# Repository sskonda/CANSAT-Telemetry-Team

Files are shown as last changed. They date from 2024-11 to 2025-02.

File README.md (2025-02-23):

# Telemetry Subsystem for SSDC CANSAT Competition  

## Overview  
This repository contains the telemetry subsystem code and resources for the SSDC CANSAT competition. It focuses on the integration and operation of sensors, motors, and the power subsystem, which are essential components for gathering, processing, and transmitting flight data. The repository does **not** include the flight software but provides all necessary libraries, configuration files, and guidelines for testing and deploying individual components.

## Project Background  
The CANSAT competition involves designing a small satellite (payload) and container that are deployed from a rocket. Upon reaching peak altitude, the container descends using a parachute, while the payload separates mid-flight and uses an auto-gyro system for controlled descent. During the mission, the payload must transmit telemetry data to the ground station at 1 Hz. 

The telemetry subsystem covered in this repository includes the following key responsibilities:
- **Collecting sensor data**: temperature, battery voltage, altitude, gyro rotation rate, acceleration, magnetic field, and GPS coordinates.
- **Managing power subsystems** to ensure consistent operation throughout the flight.
- **Handling data transmission** to the ground station.

## Repository Structure  
- **Individual Sensors Names**: Contains the necessary sensor and motor libraries, which must be uploaded to the microcontroller (e.g., Raspberry Pi Pico) for compatibility with the Thonny IDE.
- **CANSAT_PCB_Files**: Configuration files and scripts to manage power distribution and battery status monitoring.
- **`Sensor Integration/`**: Example code and test files for sensors such as temperature, GPS, gyroscopes, and magnetometers, ensuring accurate data collection.
- **`Motor Control/`**: Scripts to manage motors or actuators involved in the payload’s auto-gyro descent mechanism.

## Setup Instructions  
1. **Installing Libraries**:  
   - Place the include files (libraries) directly into the storage of the microcontroller (such as the Raspberry Pi Pico) to use them in Thonny.  
   - Main scripts for testing can remain in the development environment on your computer.

2. **Testing the Subsystem**:  
   Use individual test scripts provided in the repository to validate each sensor and motor module. Ensure that the telemetry data is transmitted to the ground station at the required **1 Hz interval** during testing.

## Software Raspberry Pi PIco connections for CANSAT (i.e. whcih GPIO Pins are connected to What)

 - **GP 6** PWM for LED to point Bottom Camera North
 - **GP 7 PWM** for Servo to point Bottom Camera North

 - **GP 8** BMP280 SDA
 - **GP 9** BMP280 SCL

 - **GP 12** Adafruit Ultimate GPS TX (UART Transmit)
 - **GP 13** Adafruit Ultimate GPS RX (UART Receive)

 - **GP 16** BNO055 SDA
 - **GP 17** BNO055 SCL

## Contribution Guidelines  
1. **Branching**: Use feature-specific branches to add or modify subsystem components.  
2. **Documentation**: Update the README or relevant code comments with clear descriptions of any changes.  
3. **Testing**: All code must be tested on the target hardware before merging into the main branch.

## Future Work  
- Integrate all subsystem components with the flight software.  
- Conduct full end-to-end testing of telemetry data transmission to the ground station.  
- Implement fault-tolerant mechanisms for power and communication systems during flight.
- Finish Coding INA260 Sensor and adding state machine logic for the controlling of other actuators on the CANSAT
- Program and Test XBEE radios (make sure they are actually transmitting to the GUI)

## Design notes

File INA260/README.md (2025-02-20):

# MicroPython-INA260

MicroPython driver (in progress) for the TI INA260 current and power sensor. This library is heavily based on the original [Adafruit-CircuitPython-INA260](https://github.com/adafruit/Adafruit_CircuitPython_INA260) library, but changed and stripped down to work with MicroPython. This library should now be usable with boards like the [Pycom FiPy](https://pycom.io/product/fipy/).

## Usage Example

This code example is based on the usage of the [Pycom FiPy](https://pycom.io/product/fipy/).

```python
from ina260 import INA260
from machine import I2C

ina260 = INA260(I2C())

print("Current:", ina260.current)
print("Voltage:", ina260.voltage)
print("Power:", ina260.power)
```

## Disclaimer

This is a work in progress and a cross between Adafruit's library and chrisb2's [MicroPython INA219 library](https://github.com/chrisb2/pyb_ina219). The code has the basis for but lacks features like power save. Please send in a Pull Request when you want to refactor code or add features.

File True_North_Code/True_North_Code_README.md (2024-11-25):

# This is the folder for using the BNO055 sensor's magentometer to find magnetic north

## LED Compass
- Write code to find magnetic north
- Control the brightness of an LED using PWM signals from the PI pico

---

### LED Compass with Memory Management
- **Purpose:** to see where the program is crashing and to fix any potential I2C bus contentions and any repeated use of objects without proper cleanup

---

### LED Compass with Threading
- Implement multicore processing with the LED compass code
  - Core 0: Reads and displays sensor data
  - Core 1: Calculates and adjusts LED brightness via a PWM signal that responds to the calculated heading of the magnetometer
- **Problems:** errors occure when exiting the program, there seems to be more than ideal latency on the LED PWM signal

---

### Reduced Latency LED Compass with Threading code
#### Why Multi-Core Processing is Useful
Multi-core processing allows tasks to run in parallel, enabling efficient resource utilization and faster response times. In this project:
- **Core 0** is dedicated to reading sensor data from the BMP280 (temperature and pressure) and BNO055 (magnetometer).
- **Core 1** calculates the heading from the magnetometer data and updates the LED brightness through a PWM signal.

This separation ensures that computationally intensive tasks, such as heading calculation and PWM signal updates, do not block or delay the sensor reading process.

#### How Multi-Core Processing is Implemented
The project uses Python's `_thread` library to create lightweight threads:
1. **Core 0** runs the `core0_task` function:
   - Reads sensor data from the BMP280 and BNO055.
   - Updates shared magnetometer data (`mag_x`, `mag_y`) using a thread-safe **lock** to avoid race conditions.
2. **Core 1** runs the `core1_task` function:
   - Calculates the heading based on the magnetometer data.
   - Adjusts the LED's brightness using a PWM signal.

#### Safeguards Against Contentions
To ensure smooth and error-free operation in a multi-threaded environment:
1. **Shared Data Protection**:
   - Magnetometer data (`mag_x` and `mag_y`) is shared between the two threads.
   - A `data_lock` is used to ensure only one thread accesses or updates the shared data at a time.
   - This prevents race conditions and data corruption during simultaneous read/write operations.
2. **Minimal Lock Usage**:
   - Locks are held only for the brief period needed to copy the shared data, minimizing the impact on performance.

#### The `running` Variable
The `running` variable acts as a global control flag for both threads:
- **Purpose**:
  - When set to `True`, both threads execute their respective tasks.
  - When set to `False`, the threads terminate gracefully.
- **Keyboard Interrupt**:
  - Press `Ctrl+C` to trigger a `KeyboardInterrupt` in the main thread.
  - This sets `running = False`, signaling both threads to stop execution.
  - A brief delay (`sleep(0.5)`) ensures both threads exit cleanly before the program terminates.

## Servo Compass
- Modify the first iteration code to work with a 360 degree servo motor
  - The Servo motor should point north at all times, taking input from the gyroscope to know which way it should adjust

## Camera Compass
- Modify the code so that it points the camera to the direction of magnetic north and keeps it there, adjusting for any movement by taking readings from the Gyroscope

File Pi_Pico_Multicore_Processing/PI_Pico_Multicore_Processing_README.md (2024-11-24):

# This is the Folder for Using Multicore Processing on a Raspberry Pi Pico

## Overview
This folder contains code and resources for implementing multicore processing on a Raspberry Pi Pico. The goal is to explore how multicore processing works and to optimize telemetry tasks for lower latency and higher efficiency.

## Test Folder
The `test` folder in this directory is intended for experimenting with multicore processing. Basic examples will demonstrate how to utilize both cores of the Raspberry Pi Pico. These examples will serve as a foundation for splitting telemetry tasks across cores effectively.

## Task Allocation for Multicore Processing
To ensure efficient parallelism and reduced latency, we propose the following allocation of tasks:

### Core 0 (Primary Core)
- **Sensor Data Acquisition**: Handles communication with sensors (e.g., BMP280, magnetometer) via I2C or SPI.
- **Data Processing**: Computes derived values such as altitude, heading, or tilt from raw sensor data.

### Core 1 (Secondary Core)
- **Data Transmission**: Formats and transmits telemetry data via communication interfaces (e.g., UART, LoRa, or Wi-Fi).
- **Data Logging**: Saves data to an SD card or other storage to ensure no loss of critical telemetry information.

## Getting Started
1. Clone the repository and navigate to the `Pi_Pico_Multicore_Processing` folder.
2. Explore the `test` folder to familiarize yourself with basic multicore processing examples.
3. Modify the provided code to integrate your sensor data acquisition and telemetry transmission tasks.

## References
- [Raspberry Pi Pico Python SDK Documentation](https://datasheets.raspberrypi.com/pico/raspberry-pi-pico-python-sdk.pdf)
- [Raspberry Pi Pico SDK GitHub Repository](https://github.com/raspberrypi/pico-sdk)
- [Rasberry Pi Pico Getting Started](https://www.raspberrypi.com/documentation/microcontrollers/micropython.html)

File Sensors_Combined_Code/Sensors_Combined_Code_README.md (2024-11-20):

# Sensors Combined Code

## First Iteration
- Combine the BNO055 sensor code and the BMP280 sensor code so that both sensors readings are being displayed at the same time

## Second Iteration
- Add GPS code to the existing code with the BMP280 and the BNO055 sensor so that all telemetry data is being displayed at the same time

## Third Iteration
- Integrate XBEE radio transmitter and receiver to the code so that the telemetry system data collected from the BNO055, BMP280, and the Adafruit Ultimate GPS is transmitted to another XBEE radio that is connected to the ground station, to ensure packets are recieved with minimal loss

## Fourth Iteration
- Add Magnetometer code so that the servo motor controls the ESP32 CAM direction and makes it face in the direction of magnetic North at all times

## Fifth Iteration
- Add code to toggle a GPIO port to turn on both cameras in the onboard telemetry system with a command from the ground stationn GUI

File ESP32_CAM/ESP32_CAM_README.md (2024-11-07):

This is the folder for all the ESP32 CAM code. 

Files included should be 

- live streaming video from ESP32 CAM
- Recording video from ESP32 CAM and writing it to an SD Card
- Moving the ESP32 CAM to tru north using a DC motor

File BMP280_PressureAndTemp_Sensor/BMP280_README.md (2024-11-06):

#BMP280 Code

This is the Airpressure sensor, temperature sennsor, and humidity sensor

##Pseudo code for how to initialize sensor

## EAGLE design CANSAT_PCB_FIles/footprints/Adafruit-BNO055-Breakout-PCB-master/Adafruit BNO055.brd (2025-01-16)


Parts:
C1, C2: 22pF; 0805-NO
C3: 0.1uF; 0805-NO
C4: 0.1uF; 0805_10MGAP
C5: 10uF; 0805-NO
C6: 10uF; 0805_10MGAP
D1: 1n4148; SOD-323
FID1, FID2: FIDUCIAL""; FIDUCIAL_1MM
JP1: HEADER-1X676MIL; 1X06_ROUND_76
JP2: HEADER-1X476MIL; 1X04_ROUND_76
Q1, Q2: BSS138; SOT23-WIDE
R3, R4, R5, R6, R7, R10: 10K; 0805-NO
R8, R9: 10K; _0805MP
U1: MIC5225-3.3; SOT23-5
U$2: BNO055
U$29, U$30, U$31, U$32: MOUNTINGHOLE2.5_THICK; MOUNTINGHOLE_2.5_PLATED_THICK
Y1: 32.768kHz; CRYSTAL_8X3.8

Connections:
3.3V: C4.2, C6.1, JP1.2, Q1.1 (G), Q2.1 (G), R6.2, R7.2, R10.2, U1.5 (OUT), U$2.3 (VDD), U$2.4 (NBOOT_LOAD_PIN), U$2.28 (VDDIO)
5.0V: C5.1, JP1.1, R8.2, R9.2, U1.1 (IN), U1.3 (EN)
GND: C1.1, C2.1, C3.1, C4.1, C5.2, C6.2, JP1.3, R3.2, R4.2, R5.2, U1.2 (GND), U$2.2 (GND), U$2.10 (PIN10(GND)), U$2.15 (PIN15(GND)), U$2.16 (PIN16(GND)), U$2.18 (COM2(GND)), U$2.25 (GND)
I2CADDR_3V: JP2.4, R5.1, U$2.17 (COM3/I2C_ADDR)
INT_3V: JP2.3, U$2.14 (INT)
unnamed: C1.2, U$2.27 (XIN32), Y1.P$4 (2)
unnamed: C2.2, U$2.26 (XOUT32), Y1.P$1 (1)
unnamed: C3.2, U$2.9 (CAP)
NRESET_3V: D1.A, R10.1, U$2.11 (NRESET)
PS0_3V: JP2.1, R3.1, U$2.6 (PS0)
PS1_3V: JP2.2, R4.1, U$2.5 (PS1)
RST_5V: D1.C, JP1.6
SCL_3V: Q2.2 (S), R7.1, U$2.19 (COM1/SCL/RX)
SCL_5V: JP1.5, Q2.3 (D), R9.1
SDA_3V: Q1.2 (S), R6.1, U$2.20 (COM0/SDA/TX)
SDA_5V: JP1.4, Q1.3 (D), R8.1



Board: 2 copper layers, 26.7 x 20.3 mm, 31 parts (2 on the bottom side), 16 nets.

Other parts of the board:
U$3: PCBFEAT-REV-040
U$28: ADAFRUIT_TEXT_20MM
U$33: ADAFRUIT_2.5MM

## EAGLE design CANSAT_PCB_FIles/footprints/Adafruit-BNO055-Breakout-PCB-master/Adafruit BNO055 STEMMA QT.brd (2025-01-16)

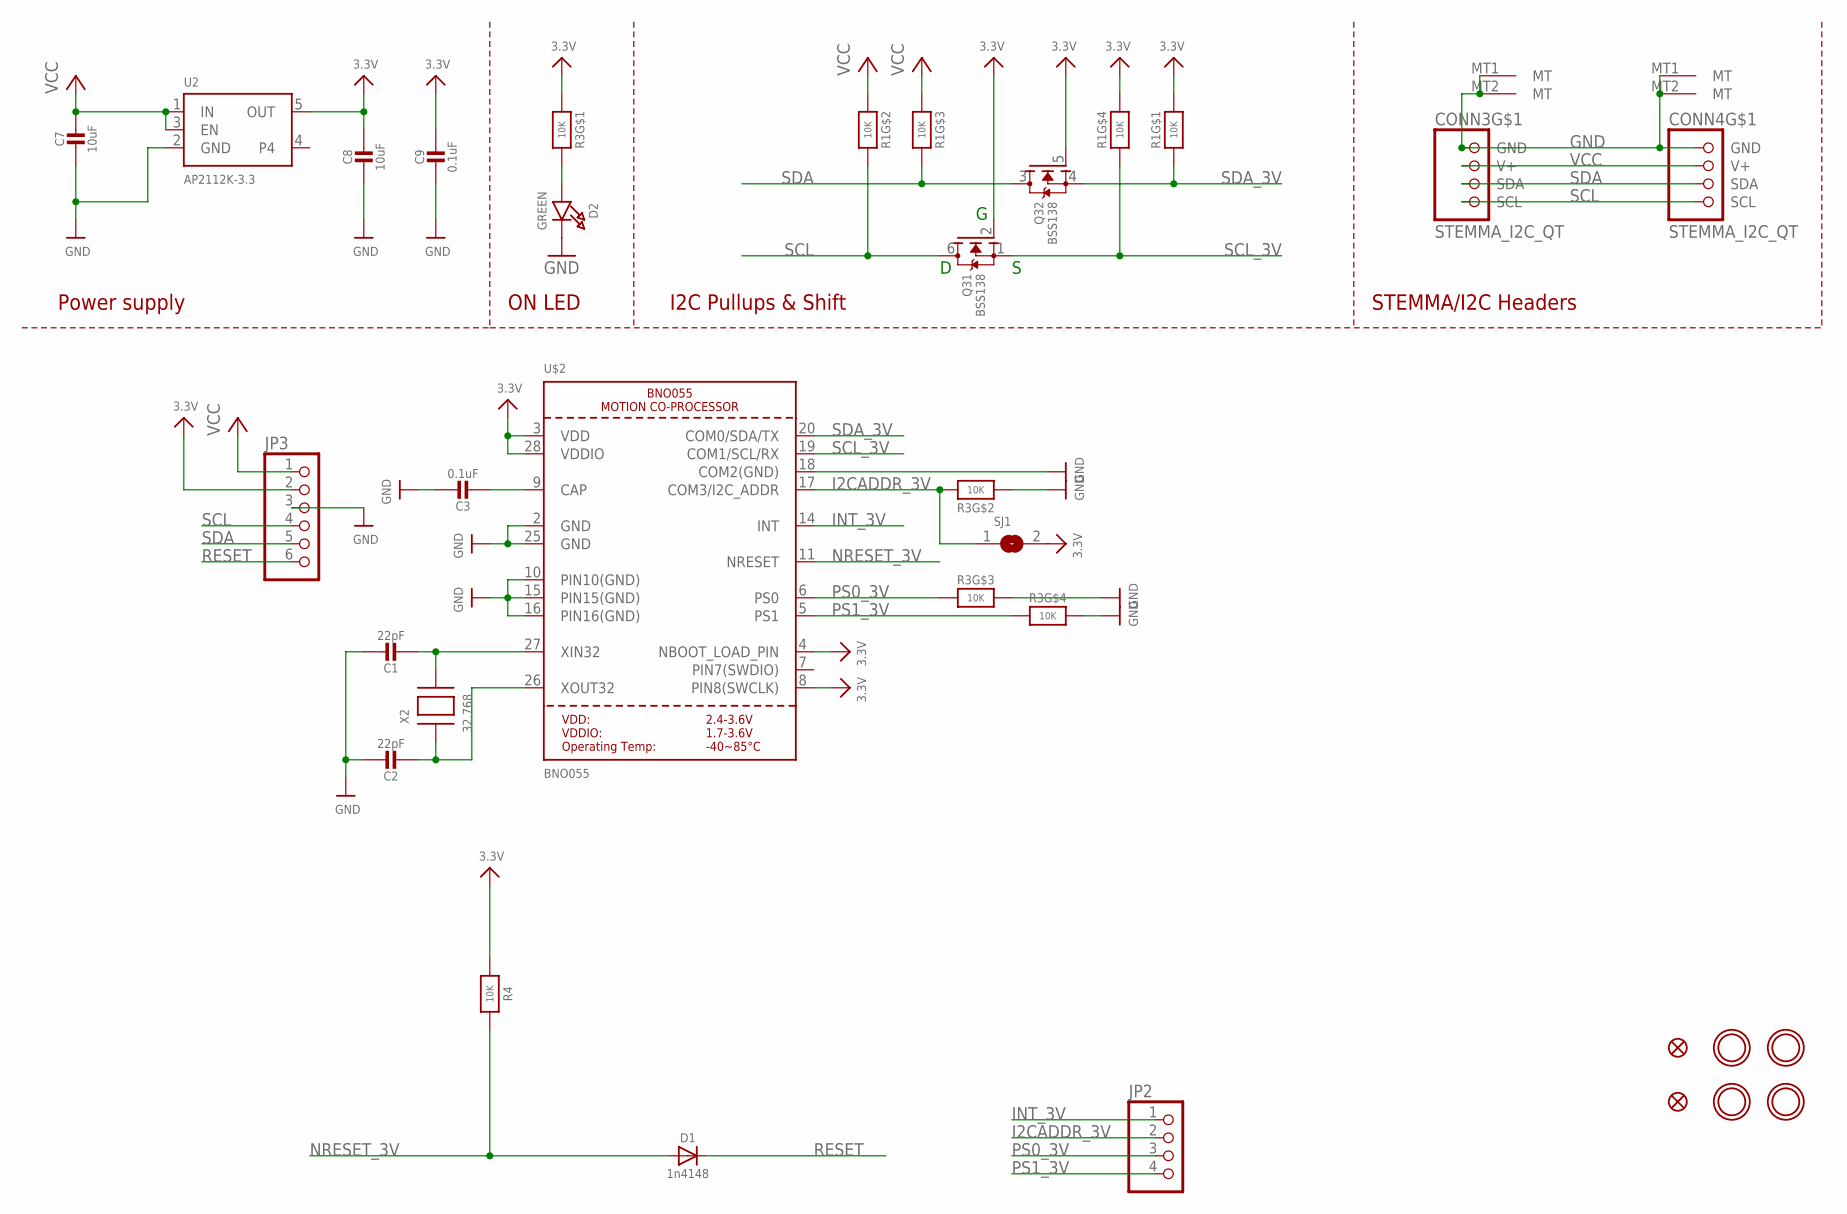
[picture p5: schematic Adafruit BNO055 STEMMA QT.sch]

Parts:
C1, C2: 22pF; 0603-NO
C3, C9: 0.1uF; 0603-NO
C7, C8: 10uF; 0805-NO
CONN3, CONN4: STEMMA_I2C_QT; JST_SH4
D1: 1n4148; SOD-323
D2: GREEN; CHIPLED_0603_NOOUTLINE
FID3, FID4: FIDUCIAL_1MM
JP2: HEADER-1X476MIL; 1X04_ROUND_76
JP3: HEADER-1X670MIL; 1X06_ROUND_70
Q3: BSS138; SOT363
R1, R3: 10K; RESPACK_4X0603
R4: 10K; 0603-NO
SJ1: SOLDERJUMPER; SOLDERJUMPER_ARROW_NOPASTE
U2: AP2112K-3.3; SOT23-5
U$2: BNO055
U$45, U$46, U$48, U$49: MOUNTINGHOLE2.5; MOUNTINGHOLE_2.5_PLATED
X2: 32.768; XTAL3215

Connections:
3.3V: C8.1, C9.1, JP3.2, Q3.2 (G), Q3.5 (G), R1.1, R1.4 (1), R3.1, R4.1, SJ1.2, U2.5 (OUT), U$2.3 (VDD), U$2.4 (NBOOT_LOAD_PIN), U$2.8 (PIN8(SWCLK)), U$2.28 (VDDIO)
GND: C1.1, C2.1, C3.1, C7.2, C8.2, C9.2, CONN3.1 (GND), CONN3.MT1 (MT), CONN3.MT2 (MT), CONN4.1 (GND), CONN4.MT1 (MT), CONN4.MT2 (MT), D2.C, JP3.3, R3.2 (1), R3.5 (2), R3.6 (2), U2.2 (GND), U$2.2 (GND), U$2.10 (PIN10(GND)), U$2.15 (PIN15(GND)), U$2.16 (PIN16(GND)), U$2.18 (COM2(GND)), U$2.25 (GND)
I2CADDR_3V: JP2.2, R3.7 (2), SJ1.1, U$2.17 (COM3/I2C_ADDR)
INT_3V: JP2.1, U$2.14 (INT)
unnamed: C1.2, U$2.27 (XIN32), X2.P$2
unnamed: C2.2, U$2.26 (XOUT32), X2.P$1
unnamed: C3.2, U$2.9 (CAP)
unnamed: D2.A, R3.8 (2)
NRESET_3V: D1.A, R4.2, U$2.11 (NRESET)
PS0_3V: JP2.3, R3.3 (1), U$2.6 (PS0)
PS1_3V: JP2.4, R3.4 (1), U$2.5 (PS1)
RESET: D1.C, JP3.6
SCL: CONN3.4 (SCL), CONN4.4 (SCL), JP3.4, Q3.6 (D), R1.7 (2)
SCL_3V: Q3.1 (S), R1.5 (2), U$2.19 (COM1/SCL/RX)
SDA: CONN3.3 (SDA), CONN4.3 (SDA), JP3.5, Q3.3 (D), R1.6 (2)
SDA_3V: Q3.4 (S), R1.8 (2), U$2.20 (COM0/SDA/TX)
VCC: C7.1, CONN3.2 (V+), CONN4.2 (V+), JP3.1, R1.2 (1), R1.3 (1), U2.1 (IN), U2.3 (EN)

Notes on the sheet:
I2C Pullups & Shift
STEMMA/I2C Headers
ON LED
Power supply

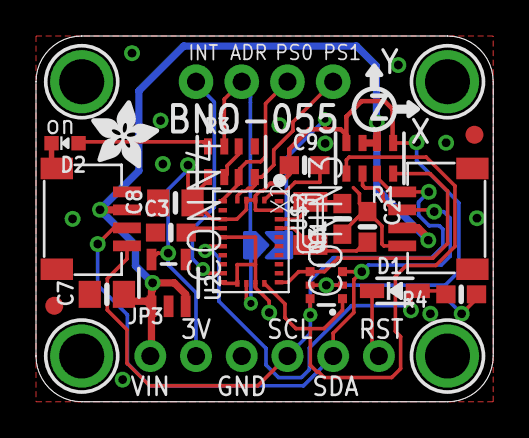
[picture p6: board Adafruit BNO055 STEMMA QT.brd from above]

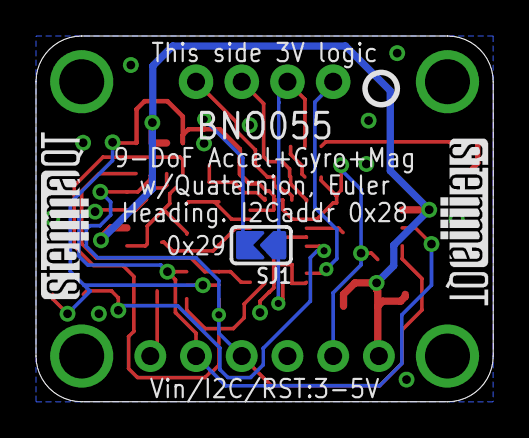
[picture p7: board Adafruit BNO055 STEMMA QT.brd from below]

Board: 2 copper layers, 25.4 x 20.3 mm, 30 parts (4 on the bottom side), 17 nets.

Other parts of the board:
U$51: ADAFRUIT_3.5MM
U$52: PCBFEAT-REV-040
U$53, U$54: STEMMAQT

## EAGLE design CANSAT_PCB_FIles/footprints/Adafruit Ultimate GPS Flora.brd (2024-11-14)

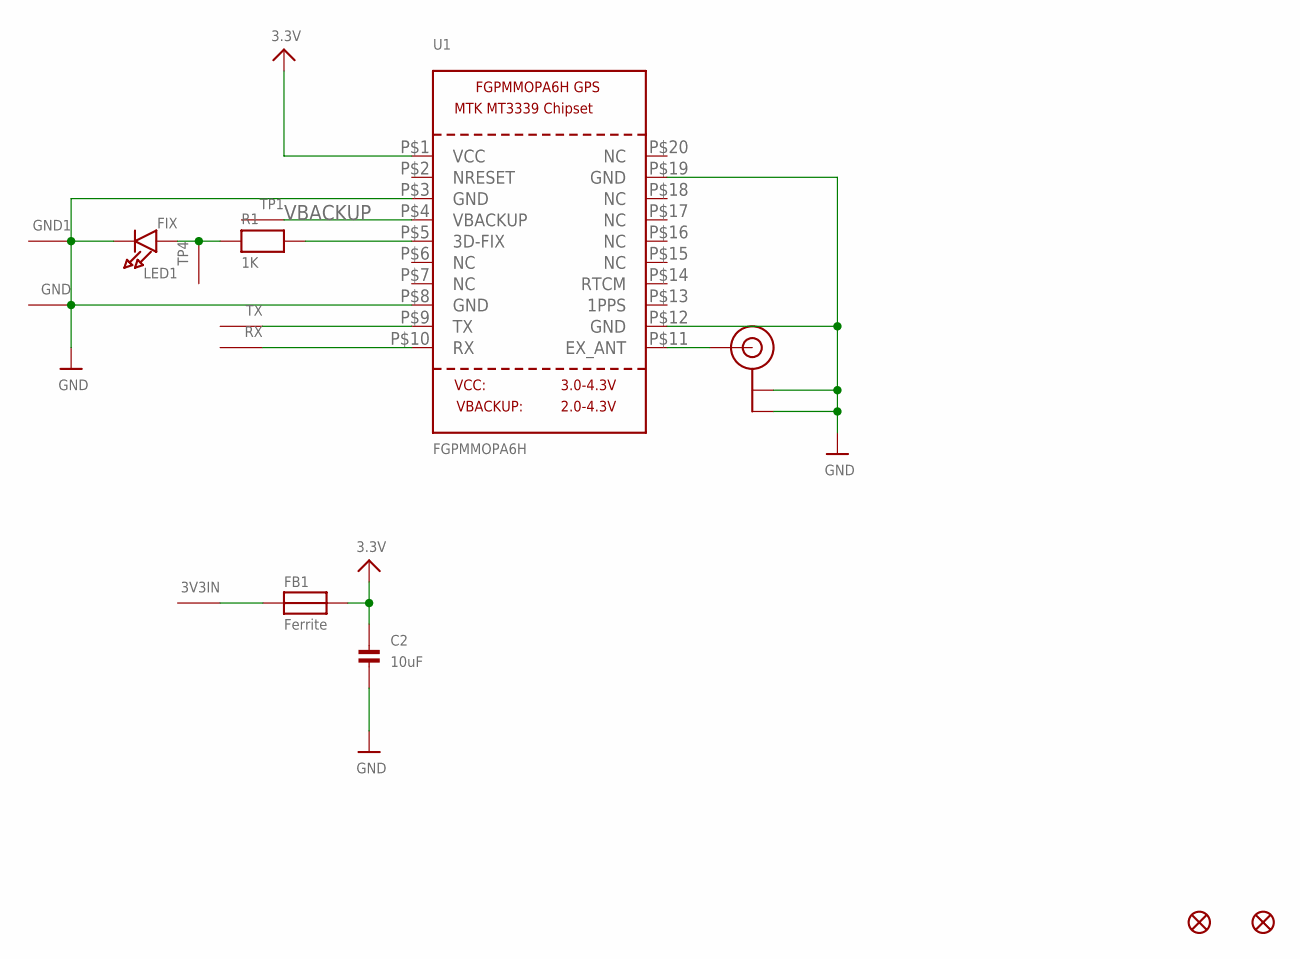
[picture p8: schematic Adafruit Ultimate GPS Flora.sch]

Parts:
3V3IN: SEWTAP-2.0IN; SEWINGTAP_2.0
C2: 10uF; 0805
FB1: Ferrite; 0805
FID1, FID2: FIDUCIAL""; FIDUCIAL_1MM
GND, GND1: SEWTAP-2.0IN; SEWINGTAP_2.0
LED1: FIX; CHIPLED_0805
R1: 1K; 0805
RX: SEWTAP-2.0IN; SEWINGTAP_2.0
TP1, TP4: SEWTAP-2.0IN; SEWINGTAP_2.0
TX: SEWTAP-2.0IN; SEWINGTAP_2.0
U1: FGPMMOPA6H
U$20: U.FL

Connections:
3.3V: C2.1, FB1.2, U1.P$1 (VCC)
GND: C2.2, GND.P$1, GND1.P$1, LED1.C, U1.P$3 (GND), U1.P$8 (GND), U1.P$12 (GND), U1.P$19 (GND), U$20.P$1 (GND), U$20.P$2 (GND)
unnamed: LED1.A, R1.1, TP4.P$1
unnamed: R1.2, U1.P$5 (3D-FIX)
unnamed: 3V3IN.P$1, FB1.1
unnamed: U1.P$11 (EX_ANT), U$20.P$3 (SIGNAL)
RX: RX.P$1, U1.P$10 (RX)
TX: TX.P$1, U1.P$9 (TX)
VBACKUP: TP1.P$1, U1.P$4 (VBACKUP)

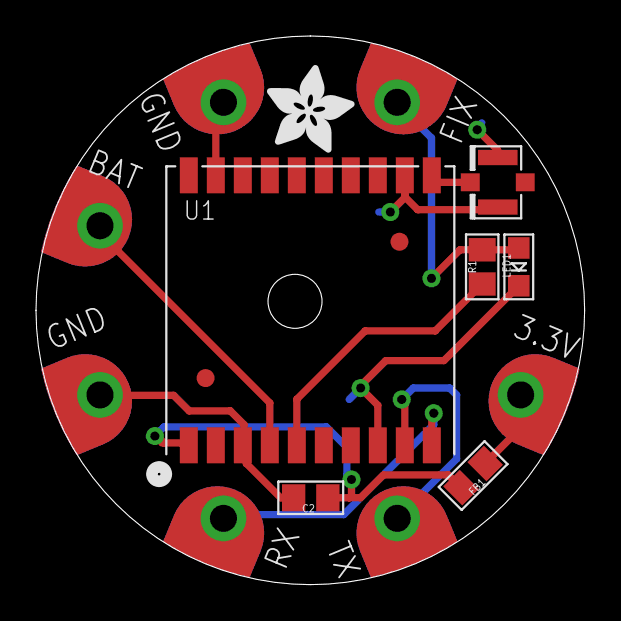
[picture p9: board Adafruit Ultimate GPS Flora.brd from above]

Board: 2 copper layers, 30.5 x 30.5 mm, 17 parts (1 on the bottom side), 9 nets.

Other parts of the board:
U$6: ADAFRUIT_5MM
U$7: FLORASMALL

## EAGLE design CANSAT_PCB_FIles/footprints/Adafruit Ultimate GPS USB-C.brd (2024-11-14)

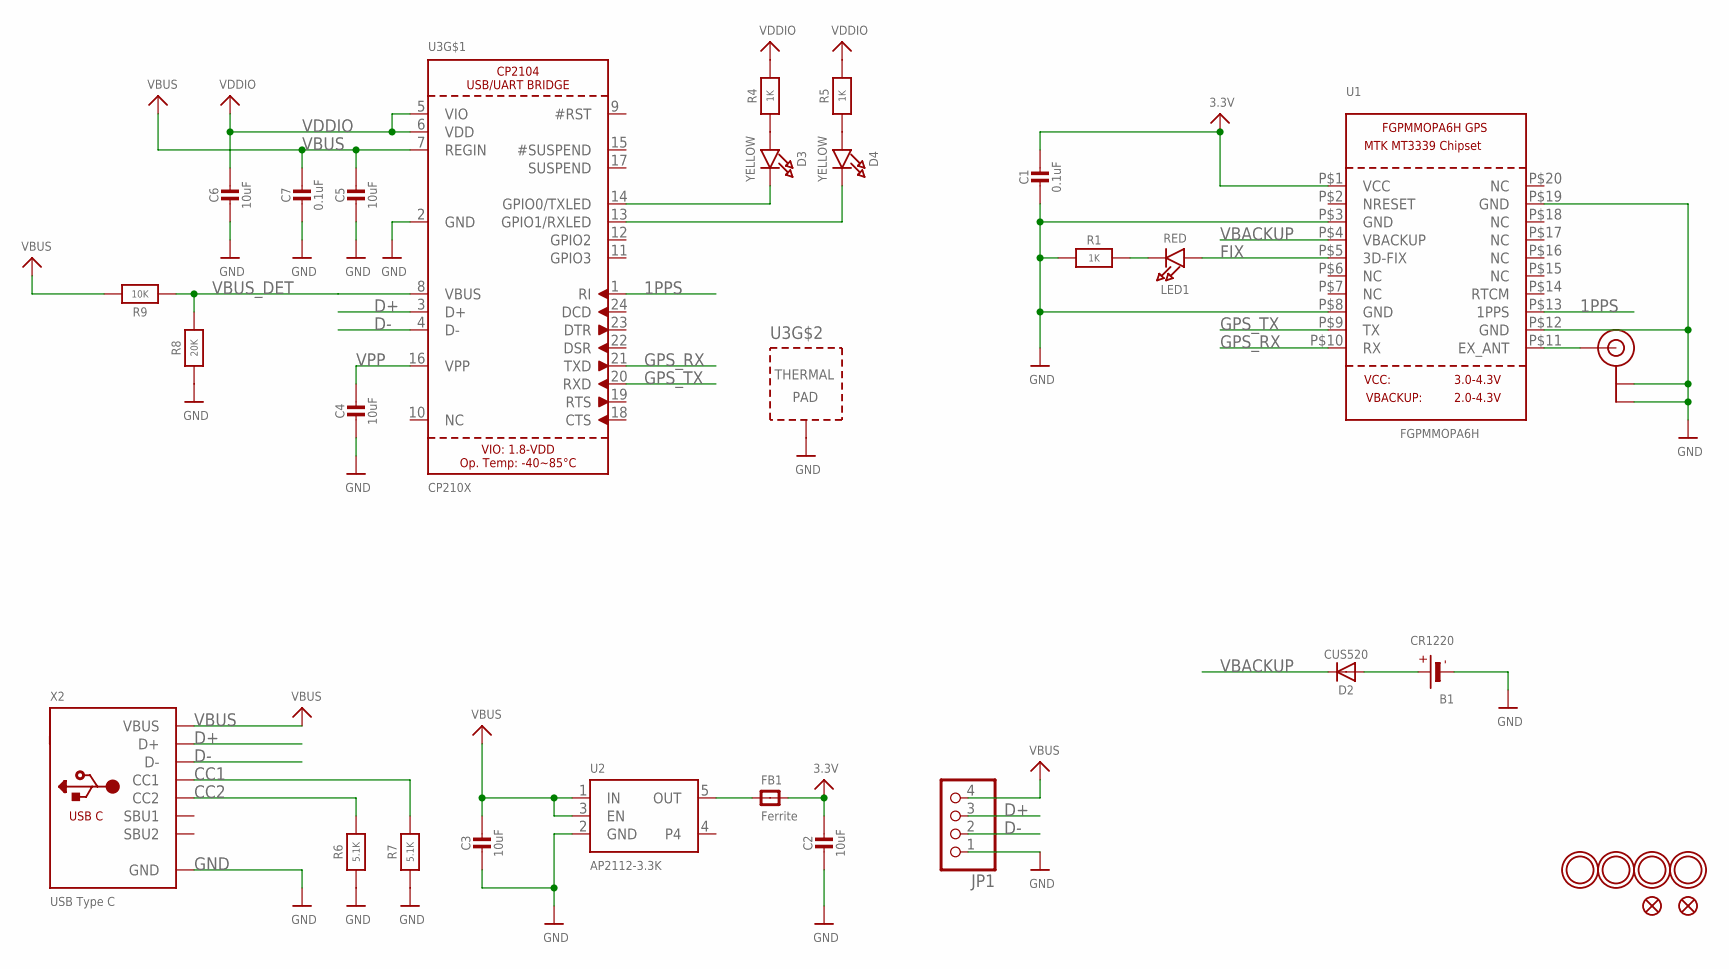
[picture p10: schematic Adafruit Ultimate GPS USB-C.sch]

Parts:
B1: CR1220
C1, C7: 0.1uF; 0603-NO
C2, C3, C4, C5, C6: 10uF; 0805-NO
D2: CUS520; SOD-323
D3, D4: YELLOW; CHIPLED_0805_NOOUTLINE
FB1: Ferrite; 0805-NO
FID1, FID2: FIDUCIAL_1MM
JP1: HEADER-1X4ROUND; 1X04_ROUND
LED1: RED; CHIPLED_0805_NOOUTLINE
R1, R4, R5: 1K; 0603-NO
R6, R7: 5.1K; 0603-NO
R8: 20K; 0603-NO
R9: 10K; 0603-NO
U1: FGPMMOPA6H
U2: AP2112-3.3K; SOT23-5
U3: CP210X; QFN24_4MM_SMSC
U$8, U$9, U$35, U$36: MOUNTINGHOLE2.5; MOUNTINGHOLE_2.5_PLATED
U$20: U.FL
X2: USB Type C; USB_C_CUSB31-CFM2AX-01-X

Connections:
1PPS: U1.P$13 (1PPS), U3.1 (RI)
3.3V: C1.1, C2.1, FB1.2, U1.P$1 (VCC)
CC1: R7.2, X2.A5 (CC1)
CC2: R6.2, X2.B5 (CC2)
D+: JP1.3, U3.3 (D+), X2.A6 (D+), X2.B6 (D+)
D-: JP1.2, U3.4 (D-), X2.A7 (D-), X2.B7 (D-)
FIX: LED1.A, U1.P$5 (3D-FIX)
GND: B1.-, C1.2, C2.2, C3.2, C4.2, C5.2, C6.2, C7.2, JP1.1, R1.1, R6.1, R7.1, R8.1, U1.P$3 (GND), U1.P$8 (GND), U1.P$12 (GND), U1.P$19 (GND), U2.2 (GND), U3.2 (GND), U3.THERM (TP), U$20.P$1 (GND), U$20.P$2 (GND), X2.A1B12 (GND), X2.B1A12 (GND)
GPS_RX: U1.P$10 (RX), U3.21 (TXD)
GPS_TX: U1.P$9 (TX), U3.20 (RXD)
unnamed: B1.+$1 (+), B1.+$2 (+), D2.A
unnamed: LED1.C, R1.2
unnamed: FB1.1, U2.5 (OUT)
unnamed: U1.P$11 (EX_ANT), U$20.P$3 (SIGNAL)
unnamed: D3.A, R4.1
unnamed: D4.A, R5.1
unnamed: D3.C, U3.14 (GPIO0/TXLED)
unnamed: D4.C, U3.13 (GPIO1/RXLED)
VBACKUP: D2.C, U1.P$4 (VBACKUP)
VBUS: C3.1, C5.1, C7.1, JP1.4, R9.2, U2.1 (IN), U2.3 (EN), U3.7 (REGIN), X2.A4B9 (VBUS), X2.B4A9 (VBUS)
VBUS_DET: R8.2, R9.1, U3.8 (VBUS)
VDDIO: C6.1, R4.2, R5.2, U3.5 (VIO), U3.6 (VDD)
VPP: C4.1, U3.16 (VPP)

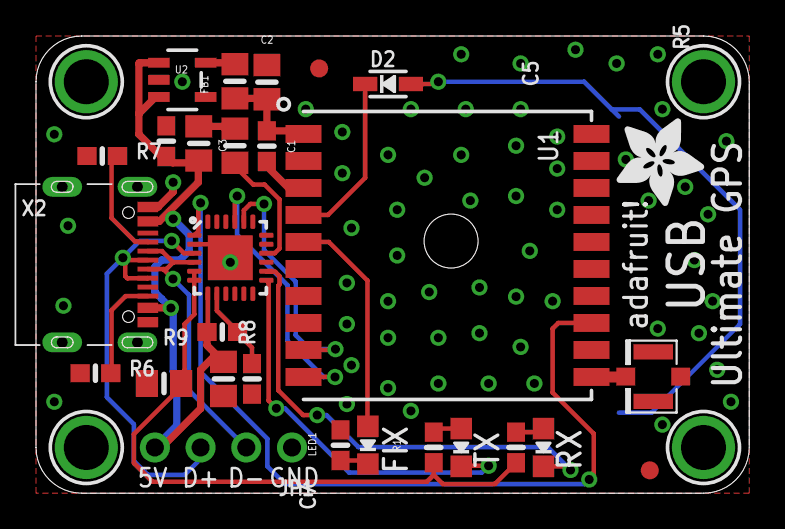
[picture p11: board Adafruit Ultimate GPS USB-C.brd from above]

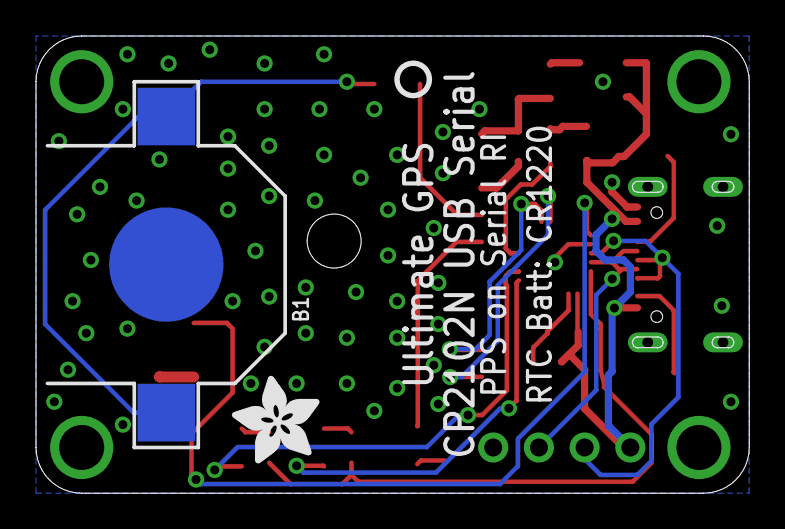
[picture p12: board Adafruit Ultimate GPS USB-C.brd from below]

Board: 2 copper layers, 39.6 x 25.4 mm, 35 parts (3 on the bottom side), 23 nets.

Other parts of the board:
U$13, U$18: ADAFRUIT_5MM
U$16: PCBFEAT-REV-040

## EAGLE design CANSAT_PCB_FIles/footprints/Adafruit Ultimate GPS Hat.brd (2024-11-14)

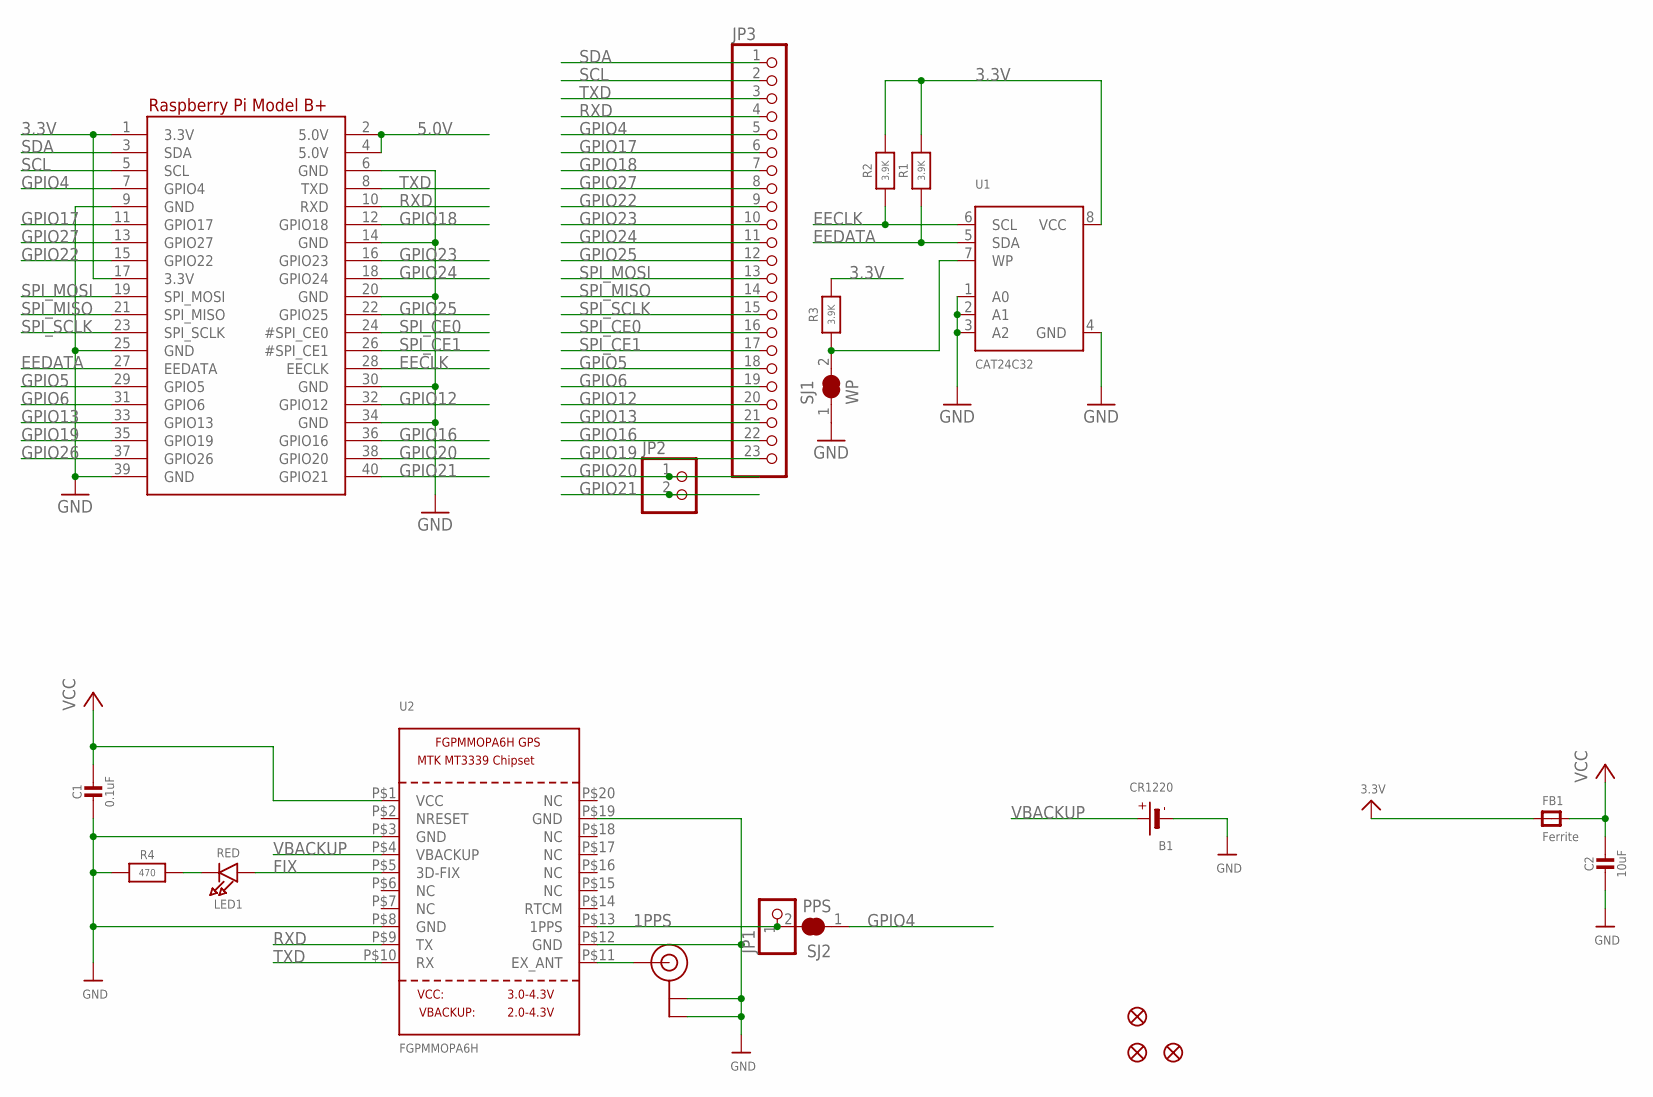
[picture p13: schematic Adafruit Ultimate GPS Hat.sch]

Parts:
B1: CR1220
C1: 0.1uF; 0805-NO
C2: 10uF; 0805-NO
FB1: Ferrite; 0805
FID1, FID2, FID3: FIDUCIAL_1MM
JP1: PINHD-1X1CB; 1X01-CLEANBIG
JP2: HEADER-1X2ROUND; 1X02_ROUND
JP3: HEADER-1X23; 1X23_ROUND_70MIL
LED1: RED; CHIPLED_0805
R1, R2, R3: 3.9K; 0805-NO
R4: 470; 0805-NO
RPI1: RASPBERRYPI_BPLUS_HATSLOTS; PI_HAT_SLOTS
SJ1: WP; SOLDERJUMPER_CLOSEDWIRE
SJ2: PPS; SOLDERJUMPER_CLOSEDWIRE
U1: CAT24C32; SOIC8_150MIL
U2: FGPMMOPA6H
U$20: U.FL

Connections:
1PPS: JP1.1, SJ2.2, U2.P$13 (1PPS)
3.3V: FB1.1, R1.2, R2.2, R3.2, RPI1.1 (3.3V), RPI1.17 (3.3V), U1.8 (VCC)
5.0V: RPI1.2 (5.0V), RPI1.4 (5.0V)
EECLK: R2.1, RPI1.28 (EECLK), U1.6 (SCL)
EEDATA: R1.1, RPI1.27 (EEDATA), U1.5 (SDA)
FIX: LED1.A, U2.P$5 (3D-FIX)
GND: B1.-, C1.2, C2.2, R4.1, RPI1.6 (GND), RPI1.9 (GND), RPI1.14 (GND), RPI1.20 (GND), RPI1.25 (GND), RPI1.30 (GND), RPI1.34 (GND), RPI1.39 (GND), SJ1.1, U1.1 (A0), U1.2 (A1), U1.3 (A2), U1.4 (GND), U2.P$3 (GND), U2.P$8 (GND), U2.P$12 (GND), U2.P$19 (GND), U$20.P$1 (GND), U$20.P$2 (GND)
GPIO4: JP3.5, RPI1.7 (GPIO4), SJ2.1
GPIO5: JP3.18, RPI1.29 (GPIO5)
GPIO6: JP3.19, RPI1.31 (GPIO6)
GPIO12: JP3.20, RPI1.32 (GPIO12)
GPIO13: JP3.21, RPI1.33 (GPIO13)
GPIO16: JP3.22, RPI1.36 (GPIO16)
GPIO17: JP3.6, RPI1.11 (GPIO17)
GPIO18: JP3.7, RPI1.12 (GPIO18)
GPIO19: JP3.23, RPI1.35 (GPIO19)
GPIO20: JP2.1, RPI1.38 (GPIO20)
GPIO21: JP2.2, RPI1.40 (GPIO21)
GPIO22: JP3.9, RPI1.15 (GPIO22)
GPIO23: JP3.10, RPI1.16 (GPIO23)
GPIO24: JP3.11, RPI1.18 (GPIO24)
GPIO25: JP3.12, RPI1.22 (GPIO25)
GPIO26: RPI1.37 (GPIO26)
GPIO27: JP3.8, RPI1.13 (GPIO27)
unnamed: R3.1, SJ1.2, U1.7 (WP)
unnamed: LED1.C, R4.2
unnamed: U2.P$11 (EX_ANT), U$20.P$3 (SIGNAL)
RXD: JP3.4, RPI1.10 (RXD), U2.P$9 (TX)
SCL: JP3.2, RPI1.5 (SCL)
SDA: JP3.1, RPI1.3 (SDA)
SPI_CE0: JP3.16, RPI1.24 (#SPI_CE0)
SPI_CE1: JP3.17, RPI1.26 (#SPI_CE1)
SPI_MISO: JP3.14, RPI1.21 (SPI_MISO)
SPI_MOSI: JP3.13, RPI1.19 (SPI_MOSI)
SPI_SCLK: JP3.15, RPI1.23 (SPI_SCLK)
TXD: JP3.3, RPI1.8 (TXD), U2.P$10 (RX)
VBACKUP: B1.+$1 (+), B1.+$2 (+), U2.P$4 (VBACKUP)
VCC: C1.1, C2.1, FB1.2, U2.P$1 (VCC)


Board: 2 copper layers, 65.0 x 56.5 mm, 24 parts (0 on the bottom side), 37 nets.

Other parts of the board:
U$3: ADAFRUIT_TEXT_20MM
U$4: PIHATLOGO
U$6: PCBFEAT-REV-056

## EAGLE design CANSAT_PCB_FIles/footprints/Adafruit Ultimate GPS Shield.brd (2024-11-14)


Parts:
B1: CR1220
C1: 1uF; 0805-NO
C2, C3: 10uF; 0805-NO
CN2: MICROSD
D1: 1n4148; SOD-323
FB1: Ferrite; 0805
FID1, FID2: FIDUCIAL""; FIDUCIAL_1MM
JP1: D0-D7; 1X08-BIG
JP4: PINHD-1X8BIG; 1X08-BIG
JP6, JP9: PINHD-1X6B; 1X06-BIG
LED1: red; CHIPLED_0805_NOOUTLINE
LED4: yellow; CHIPLED_0805_NOOUTLINE
LED5: green; CHIPLED_0805_NOOUTLINE
M1: ARDUINO_R3_ICSP_NODIM; ARDUINOR3_ICSP_NODIM
R1: 1K; 0805-NO
R5: 10K; 0805-NO
R9, R10: 1k; 0805-NO
RESET: Reset; EVQ-Q2
SJ1, SJ2, SJ3: SOLDERJUMPER; SOLDERJUMPER_ARROW_NOPASTE
SW1: DPDT-EG1390; EG1390
U1: FGPMMOPA6H
U2: MIC5225-3.3; SOT23-5
U4: 4050; SOIC16
U$9: PINHD-1X10; 1X10-BIG
U$20: U.FL

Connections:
1PPS: JP6.3, U1.P$13 (1PPS)
3.3V: C2.1, CN2.4 (SD_VDD), FB1.1, JP6.6, R5.1, R10.2, U2.5 (OUT), U4.1 (VCC)
3V: JP1.4, M1.3V
+5V: C3.1, JP1.5, M1.5V, U2.1 (IN), U2.3 (EN)
A0: JP9.1, M1.A0
A1: JP9.2, M1.A1
A2: JP9.3, M1.A2
A3: JP9.4, M1.A3
A4: JP9.5, M1.A4 (A4/SDA)
A5: JP9.6, M1.A5 (A5/SCL)
AREF: M1.AREF, U$9.3
D0: JP4.1, M1.D0, SW1.O2 (O)
D1: JP4.2, M1.D1, SW1.O1 (O)
D2: JP4.3, M1.D2
D3: JP4.4, M1.D3
D4: JP4.5, M1.D4
D5: JP4.6, M1.D5
D6: JP4.7, M1.D6
D7: JP4.8, JP6.1, M1.D7, SW1.S2 (S)
D8: JP6.2, M1.D8, SW1.S1 (S), U$9.10
D9: M1.D9, U$9.9
D11: M1.D11, SJ3.2, U$9.7
D12: M1.D12, SJ2.2, U$9.6
D13: M1.D13, SJ1.2, U$9.5
FIX: LED1.A, U1.P$5 (3D-FIX)
GND: B1.-, C1.2, C2.2, C3.2, CN2.6 (GND), CN2.MT1 (GND), CN2.MT2 (GND), JP1.6, JP1.7, LED4.C, LED5.C, M1.GND, M1.GND@1 (GND), M1.GND@2 (GND), M1.GND@3 (GND), R1.1, RESET.B (S), RESET.B' (S1), U1.P$3 (GND), U1.P$8 (GND), U1.P$12 (GND), U1.P$19 (GND), U2.2 (GND), U4.8 (GND), U$9.4, U$20.P$1 (GND), U$20.P$2 (GND)
IOREF: JP1.2, M1.IOREF
MISO: CN2.7 (DATA_OUT), M1.MISO, SJ2.1
MOSI: M1.MOSI, SJ3.1, U4.5 (2A)
unnamed: C1.1, FB1.2, U1.P$1 (VCC)
unnamed: LED1.C, R1.2
unnamed: B1.+$1 (+), B1.+$2 (+), D1.A
unnamed: U1.P$11 (EX_ANT), U$20.P$3 (SIGNAL)
unnamed: LED4.A, R9.1
unnamed: LED5.A, R10.1
NC: JP1.1, M1.RESERVED
RESET: JP1.3, M1.RESET (/RESET), M1.RESET_ICSP (RST), RESET.A, RESET.A' (P1)
RX: U1.P$10 (RX), U4.12 (5Y)
RX_5V: SW1.P2, U4.11 (5A)
SCK: M1.SCK, R9.2, SJ1.1, U4.3 (1A)
SCL: M1.SCL, U$9.1
SDA: M1.SDA, U$9.2
SD_CD: CN2.CD1 (CARD_DETECT), JP6.5
SD_CS: JP6.4, M1.D10, R5.2, U4.7 (3A), U$9.8
SD_CSIN: CN2.2 (CS), U4.6 (3Y)
SD_DATAIN: CN2.3 (DATA_IN), U4.4 (2Y)
SD_SCKIN: CN2.5 (SCLK), U4.2 (1Y)
TX: SW1.P1, U1.P$9 (TX)
VBACKUP: D1.C, U1.P$4 (VBACKUP)
VIN: JP1.8, M1.VIN

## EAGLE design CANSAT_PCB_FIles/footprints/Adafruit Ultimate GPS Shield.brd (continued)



Board: 2 copper layers, 68.6 x 53.3 mm, 34 parts (4 on the bottom side), 50 nets.

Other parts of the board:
U$13: ADAFRUIT_5MM
U$15: ADAFRUIT_TEXT_30MM
U$16: PCBFEAT-REV-040

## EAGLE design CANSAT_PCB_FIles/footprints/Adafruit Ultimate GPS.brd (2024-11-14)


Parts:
B1: CR1220
C1: 0.1uF; 0805-NO
C2, C3: 10uF; 0805-NO
D1: 1N4148; SOD-323
D2: CUS520; SOD-323
FB1: Ferrite; 0805-NO
FID1, FID2: FIDUCIAL""; FIDUCIAL_1MM
JP1: HEADER-1X970MIL; 1X09_ROUND_70
LED1: RED; CHIPLED_0805
R1: 1K; 0805-NO
R2, R3: 10K; 0805-NO
U1: FGPMMOPA6H
U2: MIC5225-3.3; SOT23-5
U$8, U$9: MOUNTINGHOLE2.5; MOUNTINGHOLE_2.5_PLATED
U$20: U.FL

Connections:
1PPS: JP1.1, U1.P$13 (1PPS)
3.3V: C1.1, C2.1, FB1.2, JP1.9, R3.1, U1.P$1 (VCC)
ENABLE: JP1.8, R2.1, U2.3 (EN)
FIX: JP1.6, LED1.A, U1.P$5 (3D-FIX)
GND: B1.-, C1.2, C2.2, C3.2, JP1.3, R1.1, U1.P$3 (GND), U1.P$8 (GND), U1.P$12 (GND), U1.P$19 (GND), U2.2 (GND), U$20.P$1 (GND), U$20.P$2 (GND)
unnamed: B1.+$1 (+), B1.+$2 (+), D2.A
unnamed: LED1.C, R1.2
unnamed: FB1.1, U2.5 (OUT)
unnamed: U1.P$11 (EX_ANT), U$20.P$3 (SIGNAL)
RX: D1.C, JP1.4
RX_3V: D1.A, R3.2, U1.P$10 (RX)
TX: JP1.5, U1.P$9 (TX)
VBACKUP: D2.C, JP1.7, U1.P$4 (VBACKUP)
VIN: C3.1, JP1.2, R2.2, U2.1 (IN)

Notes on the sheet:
D1+R3 restrict RX input to 3.3V



Board: 2 copper layers, 25.4 x 34.3 mm, 22 parts (3 on the bottom side), 14 nets.

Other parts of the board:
U$15: ADAFRUIT_2.5MM
U$16: PCBFEAT-REV-040
U$18: ADAFRUIT_5MM

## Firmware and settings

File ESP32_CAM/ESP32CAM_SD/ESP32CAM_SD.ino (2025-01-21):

/*
  ESP32 CAM Camera with MicroSD storage
  esp32cam-microsd.ino
  Take picture when button pressed
  Store image on MicroSD card

  DroneBot Workshop 2022
  https://dronebotworkshop.com
*/
// Include Required Libraries

// Camera libraries
#include "esp_camera.h"
#include "soc/soc.h"
#include "soc/rtc_cntl_reg.h"
#include "driver/rtc_io.h"

// MicroSD Libraries
#include "FS.h"
#include "SD_MMC.h"

// EEPROM Library
#include "EEPROM.h"

// Use 1 byte of EEPROM space
// #define EEPROM_SIZE 1

// Counter for picture number
unsigned int pictureCount = 0;

// Pin definitions for CAMERA_MODEL_AI_THINKER
#define PWDN_GPIO_NUM     32
#define RESET_GPIO_NUM    -1
#define XCLK_GPIO_NUM      0
#define SIOD_GPIO_NUM     26
#define SIOC_GPIO_NUM     27
#define Y9_GPIO_NUM       35
#define Y8_GPIO_NUM       34
#define Y7_GPIO_NUM       39
#define Y6_GPIO_NUM       36
#define Y5_GPIO_NUM       21
#define Y4_GPIO_NUM       19
#define Y3_GPIO_NUM       18
#define Y2_GPIO_NUM        5
#define VSYNC_GPIO_NUM    25
#define HREF_GPIO_NUM     23
#define PCLK_GPIO_NUM     22

void configESPCamera() {
  // Configure Camera parameters

  // Object to store the camera configuration parameters
  camera_config_t config;

  config.ledc_channel = LEDC_CHANNEL_0;
  config.ledc_timer = LEDC_TIMER_0;
  config.pin_d0 = Y2_GPIO_NUM;
  config.pin_d1 = Y3_GPIO_NUM;
  config.pin_d2 = Y4_GPIO_NUM;
  config.pin_d3 = Y5_GPIO_NUM;
  config.pin_d4 = Y6_GPIO_NUM;
  config.pin_d5 = Y7_GPIO_NUM;
  config.pin_d6 = Y8_GPIO_NUM;
  config.pin_d7 = Y9_GPIO_NUM;
  config.pin_xclk = XCLK_GPIO_NUM;
  config.pin_pclk = PCLK_GPIO_NUM;
  config.pin_vsync = VSYNC_GPIO_NUM;
  config.pin_href = HREF_GPIO_NUM;
  config.pin_sscb_sda = SIOD_GPIO_NUM;
  config.pin_sscb_scl = SIOC_GPIO_NUM;
  config.pin_pwdn = PWDN_GPIO_NUM;
  config.pin_reset = RESET_GPIO_NUM;
  config.xclk_freq_hz = 40000000;
  config.pixel_format = PIXFORMAT_JPEG; // Choices are YUV422, GRAYSCALE, RGB565, JPEG

  // Select lower framesize if the camera doesn't support PSRAM
  if (psramFound()) {
    config.frame_size = FRAMESIZE_VGA; // FRAMESIZE_ + QVGA|CIF|VGA|SVGA|XGA|SXGA|UXGA
    config.jpeg_quality = 40; //10-63 lower number means higher quality
    config.fb_count = 2;
  } else {
    // config.frame_size = FRAMESIZE_SVGA;
    // config.jpeg_quality = 12;
    // config.fb_count = 1;
  }

  // Initialize the Camera
  esp_err_t err = esp_camera_init(&config);
  if (err != ESP_OK) {
    Serial.printf("Camera init failed with error 0x%x", err);
    return;
  }

  // Camera quality adjustments
  sensor_t * s = esp_camera_sensor_get();

  // BRIGHTNESS (-2 to 2)
  s->set_brightness(s, 0);
  // CONTRAST (-2 to 2)
  s->set_contrast(s, 0);
  // SATURATION (-2 to 2)
  s->set_saturation(s, 0);
  // SPECIAL EFFECTS (0 - No Effect, 1 - Negative, 2 - Grayscale, 3 - Red Tint, 4 - Green Tint, 5 - Blue Tint, 6 - Sepia)
  s->set_special_effect(s, 0);
  // WHITE BALANCE (0 = Disable , 1 = Enable)
  s->set_whitebal(s, 0);
  // AWB GAIN (0 = Disable , 1 = Enable)
  s->set_awb_gain(s, 0);
  // WB MODES (0 - Auto, 1 - Sunny, 2 - Cloudy, 3 - Office, 4 - Home)
  s->set_wb_mode(s, 0);
  // EXPOSURE CONTROLS (0 = Disable , 1 = Enable)
  s->set_exposure_ctrl(s, 0);
  // AEC2 (0 = Disable , 1 = Enable)
  s->set_aec2(s, 0);
  // AE LEVELS (-2 to 2)
  s->set_ae_level(s, 0);
  // AEC VALUES (0 to 1200)
  s->set_aec_value(s, 300);
  // GAIN CONTROLS (0 = Disable , 1 = Enable)
  s->set_gain_ctrl(s, 1);
  // AGC GAIN (0 to 30)
  s->set_agc_gain(s, 0);
  // GAIN CEILING (0 to 6)
  s->set_gainceiling(s, (gainceiling_t)0);
  // BPC (0 = Disable , 1 = Enable)
  s->set_bpc(s, 0);
  // WPC (0 = Disable , 1 = Enable)
  s->set_wpc(s, 1);
  // RAW GMA (0 = Disable , 1 = Enable)
  s->set_raw_gma(s, 1);
  // LENC (0 = Disable , 1 = Enable)
  s->set_lenc(s, 1);
  // HORIZ MIRROR (0 = Disable , 1 = Enable)
  s->set_hmirror(s, 0);
  // VERT FLIP (0 = Disable , 1 = Enable)
  s->set_vflip(s, 0);
  // DCW (0 = Disable , 1 = Enable)
  s->set_dcw(s, 1);
  // COLOR BAR PATTERN (0 = Disable , 1 = Enable)
  s->set_colorbar(s, 0);

}

void initMicroSDCard() {
  // Start the MicroSD card

  Serial.println("Mounting MicroSD Card");
  if (!SD_MMC.begin("/sdcard", true)) {
    Serial.println("MicroSD Card Mount Failed");
    return;
  }
  uint8_t cardType = SD_MMC.cardType();
  if (cardType == CARD_NONE) {
    Serial.println("No MicroSD Card found");
    return;
  }

}

void takeNewPhoto(String path) {
  // Take Picture with Camera

  // Setup frame buffer
  camera_fb_t  * fb = esp_camera_fb_get();

  if (!fb) {
    Serial.println("Camera capture failed");
    return;
  }

  // Save picture to microSD card
  fs::FS &fs = SD_MMC;
  File file = fs.open(path.c_str(), FILE_WRITE);
  if (!file) {
    Serial.println("Failed to open file in write mode");
  }
  else {
    file.write(fb->buf, fb->len); // payload (image), payload length
    Serial.printf("Saved file to path: %s\n", path.c_str());
  }
  // Close the file
  file.close();

  // Return the frame buffer back to the driver for reuse
  esp_camera_fb_return(fb);
}

void setup() {

  // Disable brownout detector
  WRITE_PERI_REG(RTC_CNTL_BROWN_OUT_REG, 0);

  // Start Serial Monitor
  Serial.begin(115200);

  // Initialize the camera
  Serial.print("Initializing the camera module...");
  configESPCamera();
  Serial.println("Camera OK!");

  // Initialize the MicroSD
  Serial.print("Initializing the MicroSD card module... ");
  initMicroSDCard();

}

void loop() {
  static char path[32];
  snprintf(path, sizeof(path), "/image%d.jpg", pictureCount++);
  takeNewPhoto(String(path));
}

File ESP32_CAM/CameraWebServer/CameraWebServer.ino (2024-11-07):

#include "esp_camera.h"
#include <WiFi.h>

// Define the SSID and Password for the Wi-Fi Access Point
const char* ssid = "GatorCam";
const char* password = "Gator1234";

// Create a WiFiServer object to listen for incoming connections
WiFiServer server(80);

// Select camera model
#define CAMERA_MODEL_AI_THINKER
#include "camera_pins.h"

void setup() {
  Serial.begin(115200);
  Serial.println();

  // Start the Wi-Fi access point
  WiFi.softAP(ssid, password);
  Serial.println("WiFi AP started");

  // Start the camera
  camera_config_t config;
  config.ledc_channel = LEDC_CHANNEL_0;
  config.ledc_timer = LEDC_TIMER_0;
  config.pin_d0 = Y2_GPIO_NUM;
  config.pin_d1 = Y3_GPIO_NUM;
  config.pin_d2 = Y4_GPIO_NUM;
  config.pin_d3 = Y5_GPIO_NUM;
  config.pin_d4 = Y6_GPIO_NUM;
  config.pin_d5 = Y7_GPIO_NUM;
  config.pin_d6 = Y8_GPIO_NUM;
  config.pin_d7 = Y9_GPIO_NUM;
  config.pin_xclk = XCLK_GPIO_NUM;
  config.pin_pclk = PCLK_GPIO_NUM;
  config.pin_vsync = VSYNC_GPIO_NUM;
  config.pin_href = HREF_GPIO_NUM;
  config.pin_sscb_sda = SIOD_GPIO_NUM;
  config.pin_sscb_scl = SIOC_GPIO_NUM;
  config.pin_pwdn = PWDN_GPIO_NUM;
  config.pin_reset = RESET_GPIO_NUM;
  config.xclk_freq_hz = 20000000;
  config.pixel_format = PIXFORMAT_JPEG;
  config.frame_size = FRAMESIZE_QVGA;
  

  if (psramFound()) {
    config.frame_size = FRAMESIZE_QVGA;
    config.jpeg_quality = 15;
    config.fb_count = 2;
  } else {
    config.frame_size = FRAMESIZE_QVGA;
    config.jpeg_quality = 12;
    config.fb_count = 1;
  }

  esp_err_t err = esp_camera_init(&config);
  if (err != ESP_OK) {
    Serial.printf("Camera init failed with error 0x%x", err);
    return;
  }

  // Initialize the camera server
  server.begin();
  Serial.println("HTTP server started");

  Serial.print("Camera Ready! Use 'http://");
  Serial.print(WiFi.softAPIP());
  Serial.println("' to connect");
}

void loop() {
  // Check if a client has connected
  WiFiClient client = server.available();
  if (client) {
    Serial.println("New client connected");
    String req = client.readStringUntil('\r');
    client.flush();

    if (req.indexOf("GET /") != -1) {
      // Send the initial HTTP headers
      client.println("HTTP/1.1 200 OK");
      client.println("Content-Type: multipart/x-mixed-replace; boundary=frame");
      client.println();

      while (client.connected()) {
        camera_fb_t *fb = esp_camera_fb_get();
        if (!fb) {
          Serial.println("Camera capture failed");
          client.stop();
          return;
        }

        // Send the current frame
        client.print("--frame\r\n");
        client.print("Content-Type: image/jpeg\r\n");
        client.print("Content-Length: ");
        client.print(fb->len);
        client.print("\r\n\r\n");
        client.write(fb->buf, fb->len);
        client.print("\r\n");
        

        esp_camera_fb_return(fb);

        // Small delay to prevent watchdog timer reset and control frame rate
        delay(10);
      }
    }

    // Close the connection
    client.stop();
    Serial.println("Client disconnected");
  }
}

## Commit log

2024-10-17 Create Gyro
2024-10-22 Create GYRO_README
2024-10-22 Organize files
    Put the Gyro code in the right folder
2024-11-06 Update GYRO_README
2024-11-07 added camera live stream code
    [partitions.csv]
2024-11-07 added files
    working livestream esp32 camera
    [partitions.csv]
2024-11-14 Added Camera code that can write to SD card and read the SD card
2024-11-19 Updated BNO055 test code
    Changed HardI2C to SoftI2C
    Figure out later how to use HardI2C and avoid weird errors in reading info from sensor
    [bno055_test.py]
2024-11-19 2 sensor integration code
    Only 2 sensors here rn though
2024-11-21 added lib file for pico
2024-11-23 modified camera live stream code
2024-11-24 restructured files and added file for parallel processing on a pi pico
    [Adafruit Ultimate GPS Featherwing.sch, Adafruit Ultimate GPS Flora.brd, Adafruit Ultimate GPS Flora.sch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]
2024-11-24 Create LED_Compass_with_memory_management.py
    Hopefully, the added memory management will tell us where the program is crashing, and will stop the program from crashing if there is a bus contention on I2C or if there is a repeated use of objects without proper cleanup
    [LED_Compass_with_memory_management.py]
2024-11-24 added comments to LED_Compass.py detailing issues
    [LED_Compass.py, LED_Compass_with_memory_management.py]
2024-11-25 made changes to multicore processing with LED compass to make the code cleanly exit
2024-12-04 Delete Sensors_Combined_Code/altitude_blueprint.py
    incorrectly adjusted variables
2025-01-15 CANSAT PCB files added
    [CANSAT_Telemetry_schematic.SchDoc]
2025-01-16 PCB Schematic and Footprints
    Made PCB Schematic connecting Raspberry Pi, BMP280, BMO055. Made new schematic and PCB library for BMP280, BMO055, and Adafruit GPS (CANSAT_Extra libraries).
    Ignore the 47 files that's because of the different versions (it's like less than 50KB don't worry)
    [CANSAT_ExtraLib.PcbLib, CANSAT_ExtraLib.SchLib, CANSAT_Telemetry_schematic.SchDoc]
2025-01-16 PCB Update
    [CANSAT_PCB.PrjPcb]
2025-01-16 moved some stuff around
    [CANSAT_Telemetry_schematic.SchDoc]
2025-01-16 fixed some errors, the footprints for the sensors still need to be made
    [Adafruit BNO055 STEMMA QT.brd, Adafruit BNO055 STEMMA QT.sch, Adafruit BNO055.brd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]
2025-01-16 idek whats different but github says something is
    [CANSAT_Telemetry_schematic_PCB.PcbDoc]
2025-01-20 changed some shit
    [CANSAT_Telemetry_schematic.SchDoc, CANSAT_Telemetry_schematic_PCB.PcbDoc]
2025-01-20 GPS using Pico
    Working GPS using the Pi Pico instead of the Arduino Nano
    Adafruit_GPS is not available in Python, so to extract the information from the NMEA sentences is more code
2025-01-21 Updated camera code to SD card at around 10 frames a second in 480p
2025-01-28 balls in your jawls
    PCB Additions
    [CANSAT_ExtraLib.PcbLib, CANSAT_ExtraLib.SchLib, CANSAT_Telemetry_schematic.SchDoc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]
2025-01-29 Updated for 180 degree servo rotation with compass
2025-02-28 Create Rotate Servo.py

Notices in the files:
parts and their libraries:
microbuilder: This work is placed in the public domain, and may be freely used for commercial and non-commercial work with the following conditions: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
